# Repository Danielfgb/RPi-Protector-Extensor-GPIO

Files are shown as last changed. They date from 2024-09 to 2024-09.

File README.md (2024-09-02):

# RPi-Protector-Extensor-GPIO
Este proyecto consiste en un módulo diseñado para proteger los pines GPIO de la Raspberry Pi y extender su funcionalidad. El módulo incluye protecciones con diodos Zener y resistencias, un extensor de pines GPIO, la capacidad de conectar un módulo relé, y un módulo de reloj en tiempo real (RTC) DS3231.

## Características:

- Protección de GPIO: Cada pin GPIO está protegido con un diodo Zener y una resistencia de 330 ohms, protegiendo los pines de la Raspberry Pi contra sobretensiones y corrientes excesivas.
- Extensión de Pines GPIO: Se incluye un extensor de pines GPIO que permite la conexión de más dispositivos o módulos adicionales.
Compatibilidad con Módulo Relé.
- RTC DS3231: Se ha agregado un módulo de reloj en tiempo real (RTC) DS3231 para mantener el tiempo con alta precisión incluso cuando la Raspberry Pi está apagada.
- Indicadores LED: Se incluyen LEDs de estado en los pines GPIO sin un consumo excesivo de corriente.

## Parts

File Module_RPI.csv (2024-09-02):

Reference | Value | Footprint | Datasheet | Description | Enlace de compra | Package | Cdad
3.3V1, 3.3V2 | Conn_01x02 | Connector_Molex:Molex_KK-254_AE-6410-02A_1x02_P2.54mm_Vertical | ~ | Conector molex P2.54mm |  | THT 2.54mm | 2
5V1, 5V2 | Conn_01x02 | Connector_Molex:Molex_KK-254_AE-6410-02A_1x02_P2.54mm_Vertical | ~ | Conector molex P2.54mm |  | THT 2.54mm | 2
BT1 | Battery | Battery:BatteryHolder_Seiko_MS621F | ~ | Bateria 3v |  |  | 1
C1, C2 | 100nF | Capacitor_SMD:C_0805_2012Metric | ~ | Condensador SMD 0805 100nF |  | 0805 | 2
D1, D30-D58 | LED | LED_SMD:LED_1206_3216Metric | ~ | LED SMD 1206 | https://www.vistronica.com/componentes-activos/diodos/led/led-verde-smd-1206-x10-detail.html | 1206 | 30
D2-D29 | BZT52Bxx | Diode_SMD:D_SOD-123F | https://www.alldatasheet.com/view.jsp?Searchword=Bzt52c3v3 | Diodo zener 3.3v SMD SOD-123F | https://www.vistronica.com/nuevo-compras-diodo-zener-33v-bzt52c3v3s-0805-detail.html | SOD-123F | 28
GPIO16, GPIO18, GPIO22, GPIO24, GPIO26, GPIO28 | Conn_01x02 | Connector_Molex:Molex_KK-254_AE-6410-02A_1x02_P2.54mm_Vertical | ~ | Conector molex P2.54mm |  | THT | 6
GPIO29 | Conn_01x03 | Connector_Molex:Molex_KK-254_AE-6410-03A_1x03_P2.54mm_Vertical | ~ | Conector molex P2.54mm |  | THT | 1
J1 | Conn_01x02_Pin | Connector_PinHeader_2.54mm:PinHeader_1x02_P2.54mm_Vertical | ~ |  |  |  | 1
J1_Rele1 | Conn_02x20_Odd_Even | Connector_PinHeader_2.54mm:PinHeader_2x20_P2.54mm_Vertical | ~ | Header macho macho 2.54mm (2x20P) | https://www.vistronica.com/conectores-cables-y-switches/regleta-conector-140p-2-54mm-macho-macho-detail.html | THT | 1
J2, J4 | Conn_01x20 | Connector_PinHeader_2.54mm:PinHeader_1x20_P2.54mm_Vertical | ~ | Header macho macho 2.54 mm (1x20P) | https://www.vistronica.com/conectores-cables-y-switches/regleta-conector-140p-2-54mm-macho-macho-detail.html | THT | 2
JP1-JP28 | Jumper_3_Bridged12 | Jumper:SolderJumper-3_P1.3mm_Open_Pad1.0x1.5mm | ~ | Pista para soldar jumper |  | None | 28
JP30 | Jumper_2_Open | Jumper:SolderJumper-2_P1.3mm_Open_RoundedPad1.0x1.5mm | ~ |  |  |  | 1
R1, R59 | 4.7K | Resistor_SMD:R_1206_3216Metric | ~ | Resistencia SMD 1206 4.7K |  | 1206 | 2
R2, R32-R58, R60-R62 | 10K | Resistor_SMD:R_1206_3216Metric | ~ | -- valores mixtos -- | -- valores mixtos -- | -- valores mixtos -- | 31
R3-R30 | 330R | Resistor_SMD:R_1206_3216Metric_Pad1.30x1.75mm_HandSolder | ~ | Resistencia SMD 1206 330 | https://www.vistronica.com/componentes-pasivos/resistencias/resistencias-330-ohm-smd-1206-14w-5-x10-detail.html | 1206 | 28
R31 | 1K | Resistor_SMD:R_1206_3216Metric | ~ | Resistencia SMD 1206 1K | https://www.vistronica.com/componentes-pasivos/resistencias/resistencias-1-kohm-smd-1206-14w-5-x10-detail.html | 1206 | 1
SW1 | SW_Push | Button_Switch_SMD:SW_SPST_TL3342 | ~ |  |  |  | 1
U1 | DS3231M | Package_SO:SOIC-16W_7.5x10.3mm_P1.27mm | http://datasheets.maximintegrated.com/en/ds/DS3231.pdf | RTC DS3231M |  | SOIC | 1
U2 | RASPBERRY_PI_4B_4GB | RASPBERRY_PI_4B_4GB:MODULE_RASPBERRY_PI_4B_4GB |  | Regleta HEMBRA 2.54mm (2X20P) | https://www.vistronica.com/conectores-cables-y-switches/regleta-hembra-254mm-2x20p-detail.html | None | 1

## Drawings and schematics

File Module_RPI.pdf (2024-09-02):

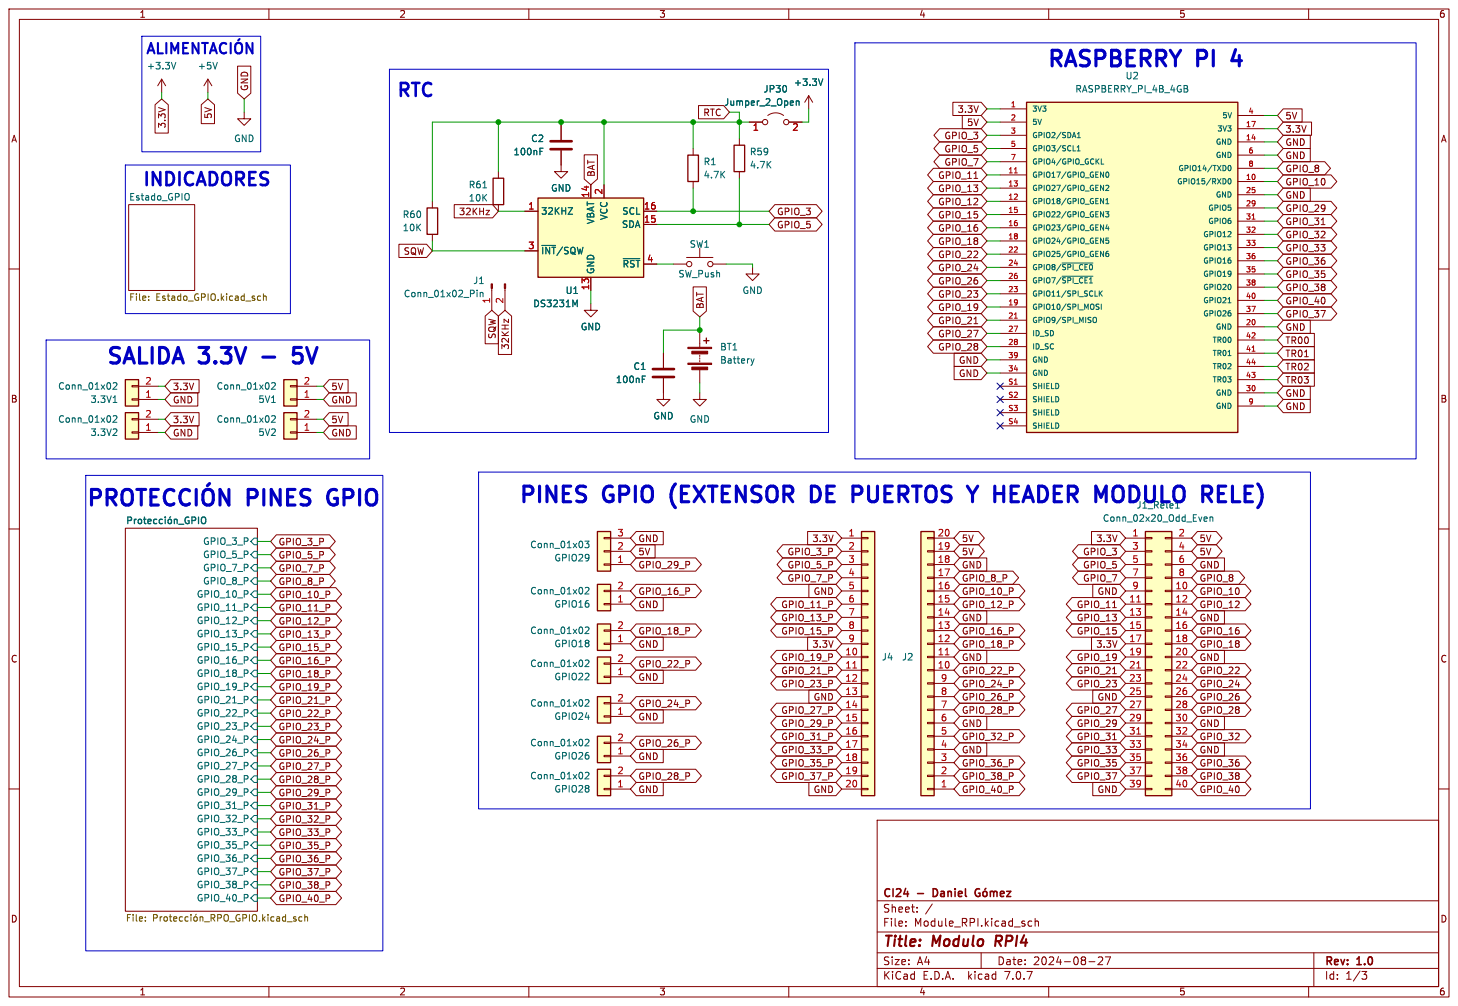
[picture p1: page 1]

PINES GPIO (EXTENSOR DE PUERTOS Y HEADER MODULO RELE)

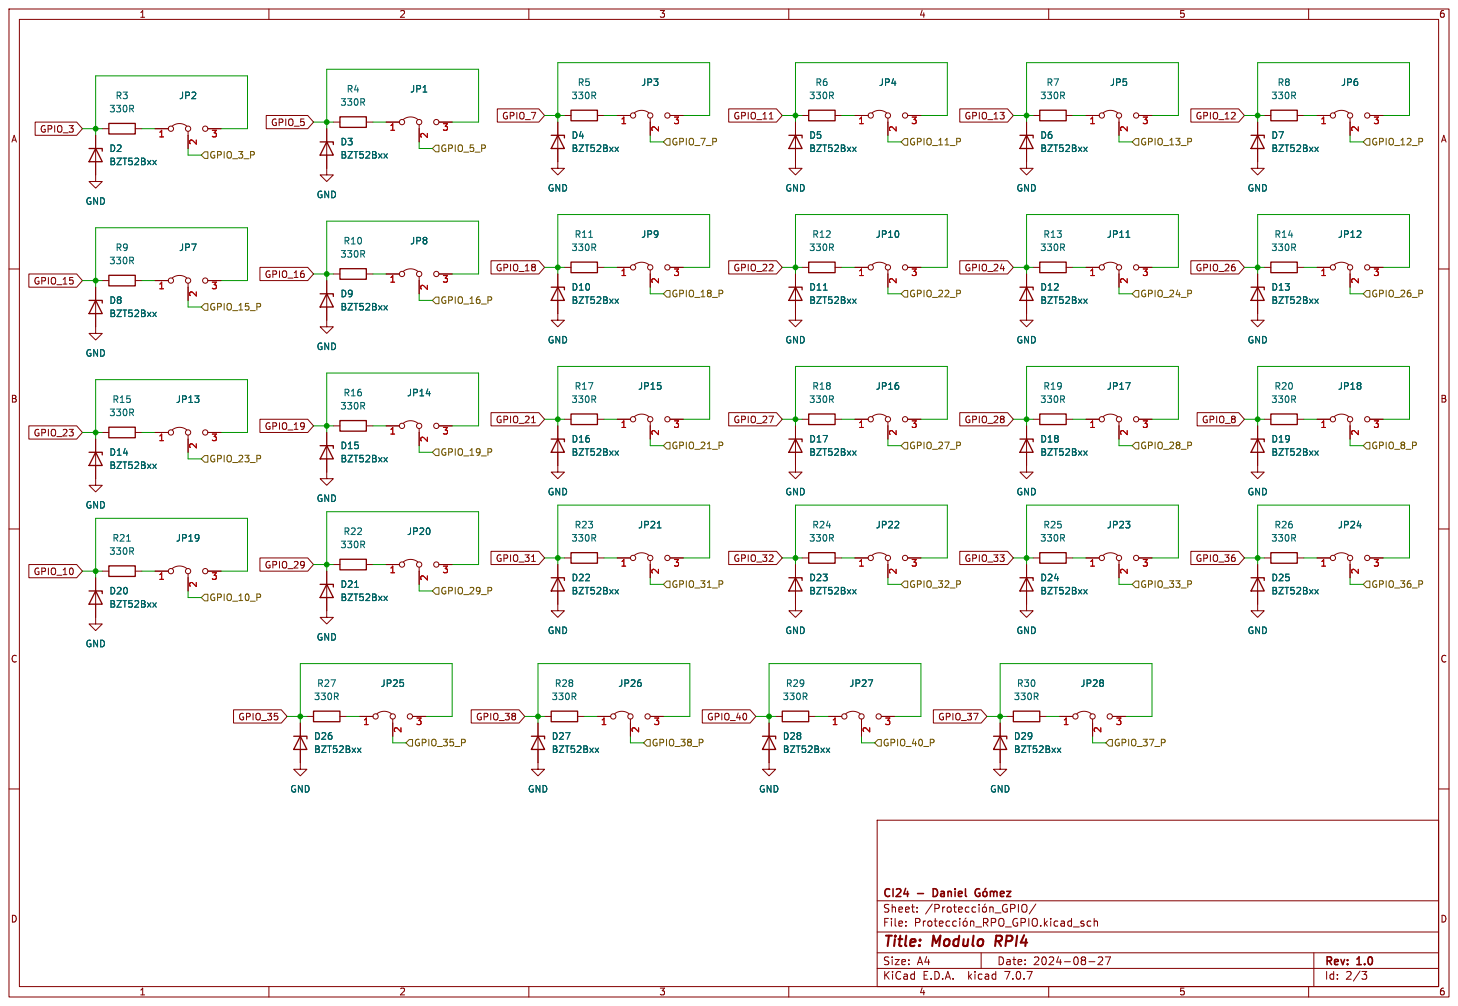
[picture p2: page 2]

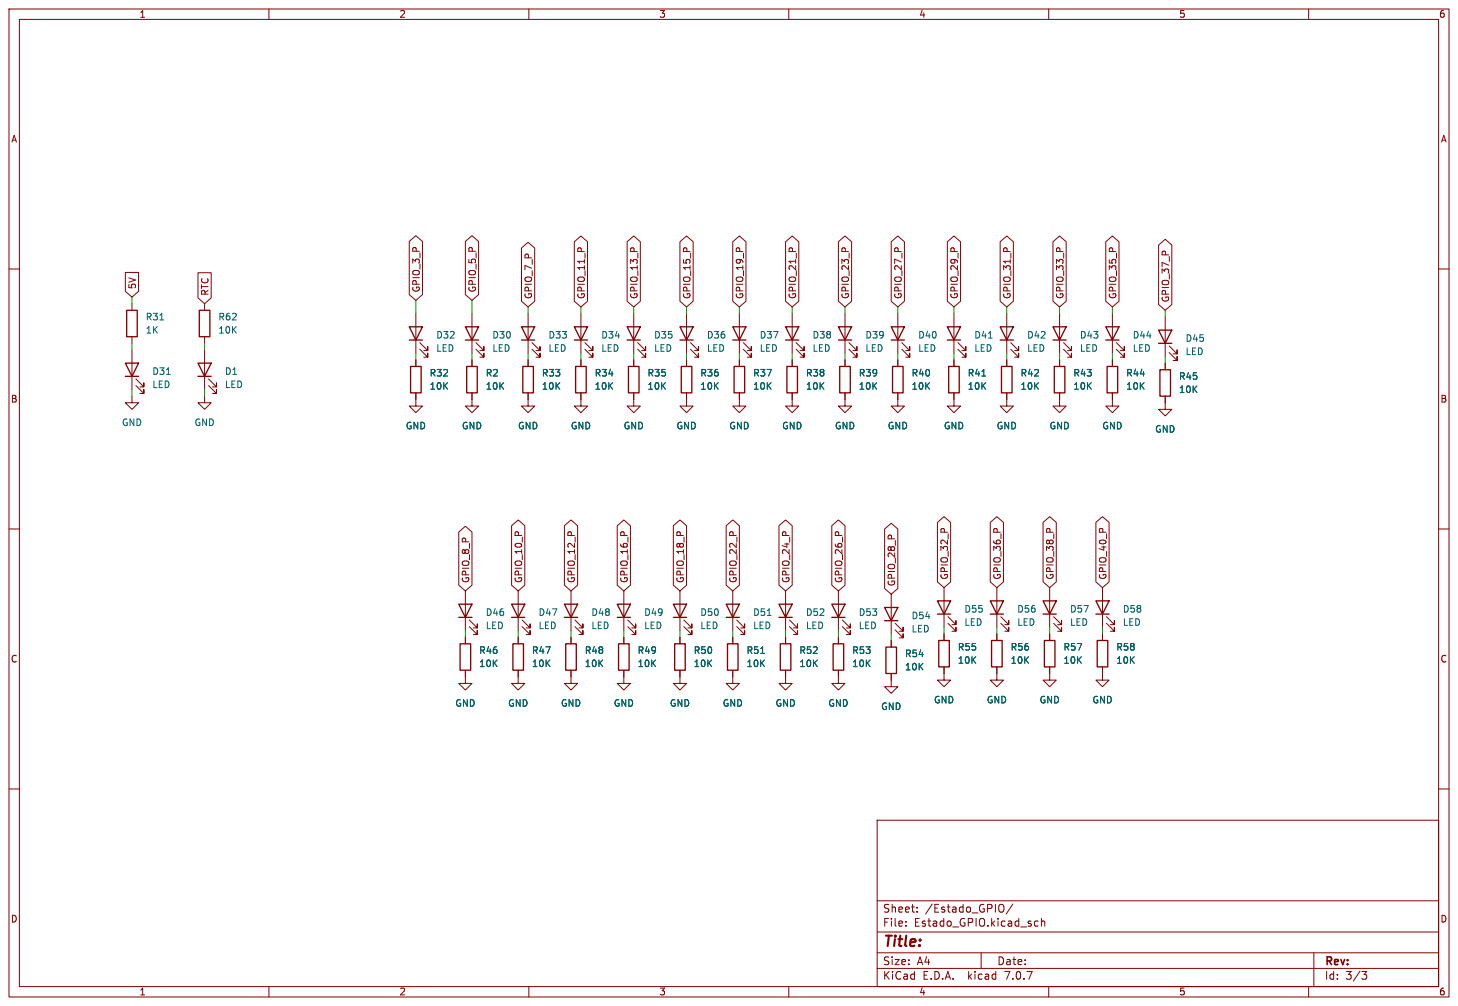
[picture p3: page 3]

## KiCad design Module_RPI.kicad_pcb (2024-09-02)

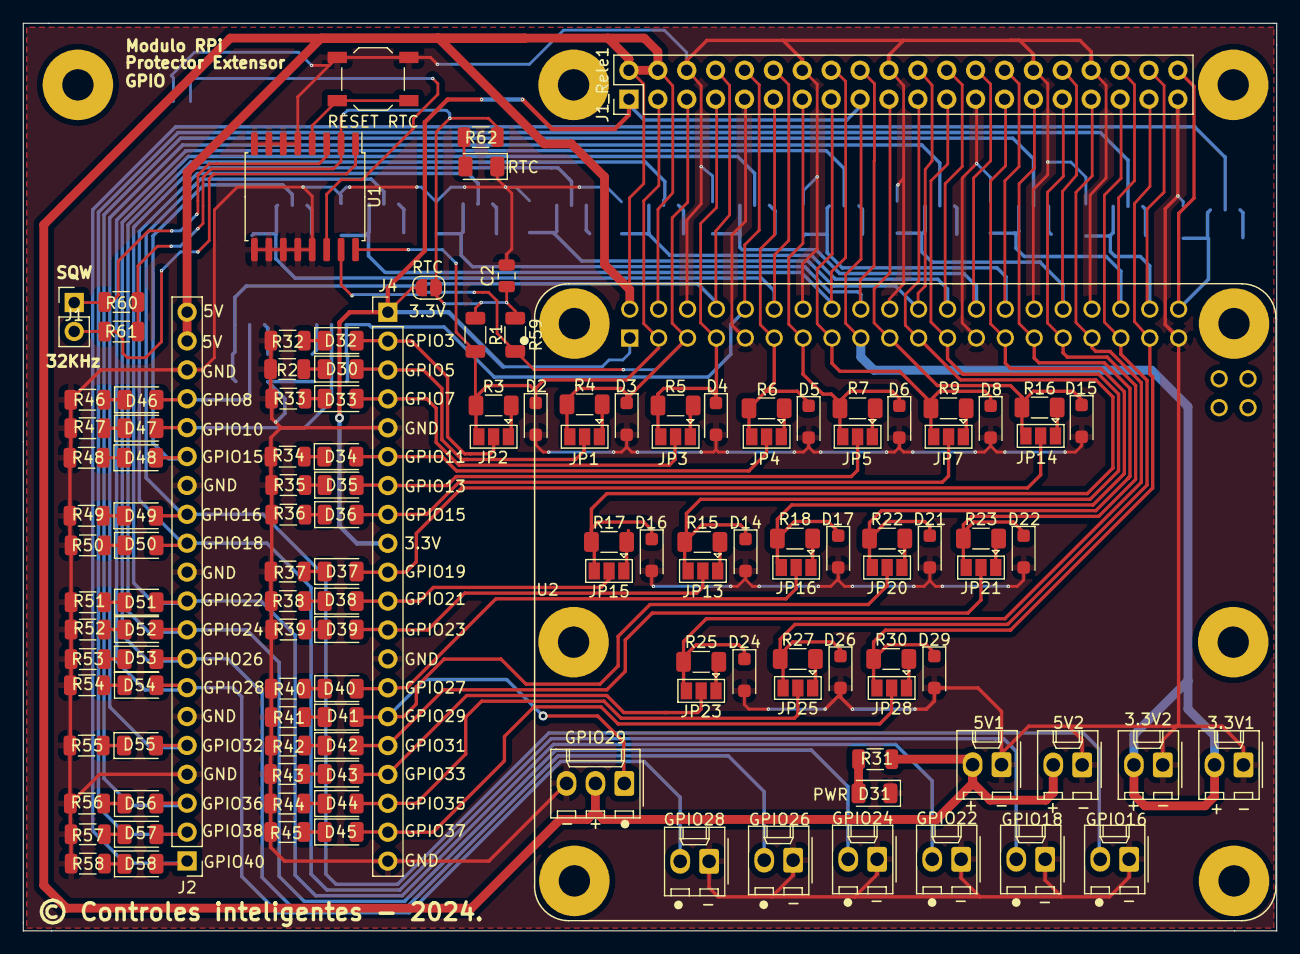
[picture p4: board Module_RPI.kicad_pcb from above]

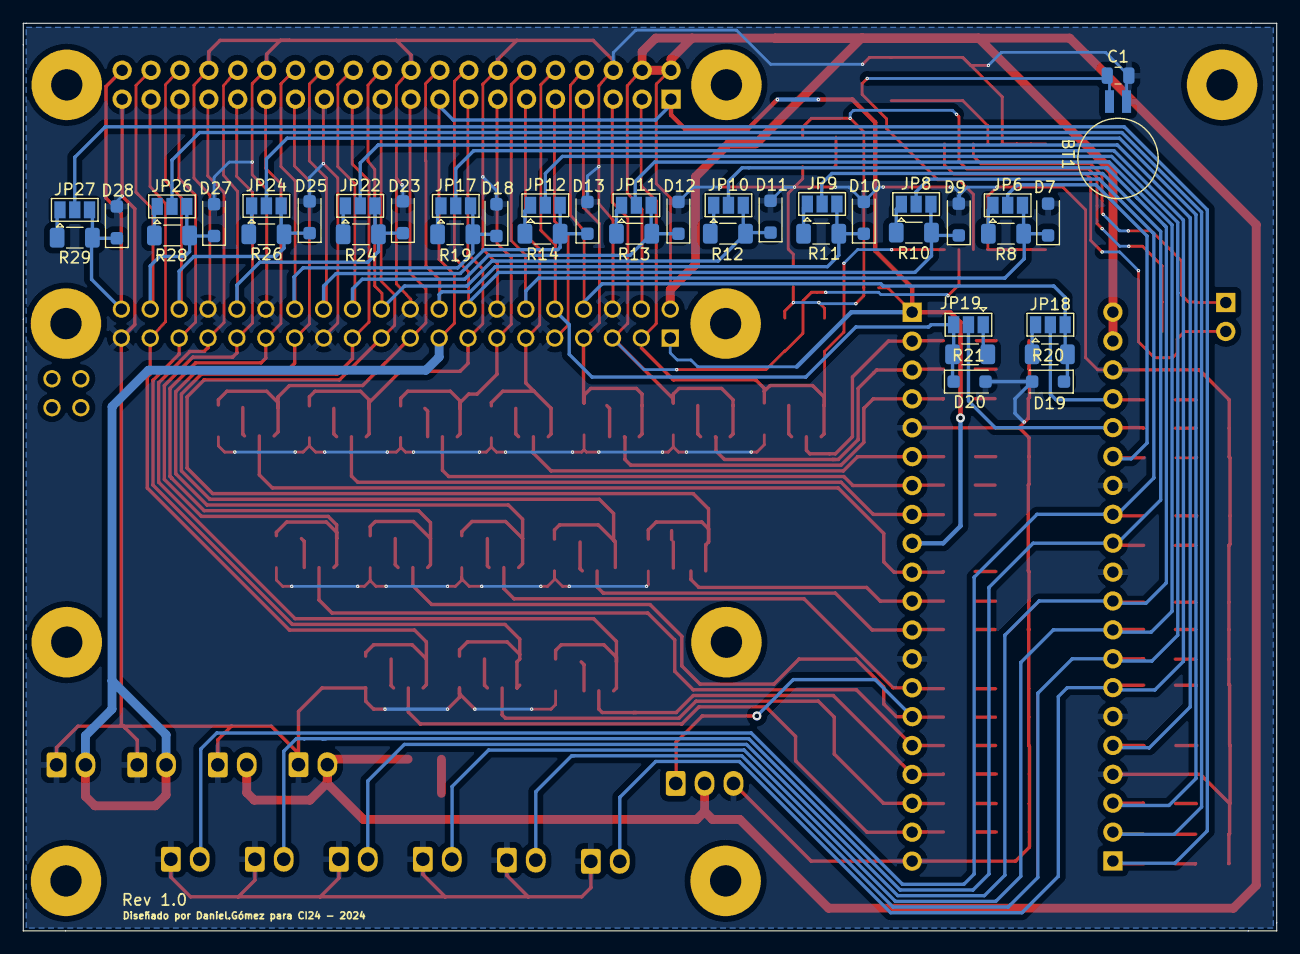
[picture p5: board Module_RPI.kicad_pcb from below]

Board: 2 copper layers, 110.2 x 79.8 mm, 170 parts (41 on the bottom side), 122 nets.

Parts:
3.3V1, 3.3V2, 5V1, 5V2: Conn_01x02; Molex_KK-254_AE-6410-02A_1x02_P2.54mm_Vertical
BT1: Battery; BatteryHolder_Seiko_MS621F
C1, C2: 100nF; C_0805_2012Metric
D2, D3, D4, D5, D6, D7, D8, D9, D10, D11, D12, D13, D14, D15, D16, D17, D18, D19, D20, D21, D22, D23, D24, D25, D26, D27, D28, D29: BZT52Bxx; D_SOD-123F
D30, D31, D32, D33, D34, D35, D36, D37, D38, D39, D40, D41, D42, D43, D44, D45, D46, D47, D48, D49, D50, D51, D52, D53, D54, D55, D56, D57, D58: LED; LED_1206_3216Metric
GPIO16, GPIO18, GPIO22, GPIO24, GPIO26, GPIO28: Conn_01x02; Molex_KK-254_AE-6410-02A_1x02_P2.54mm_Vertical
GPIO29: Conn_01x03; Molex_KK-254_AE-6410-03A_1x03_P2.54mm_Vertical
J1: Conn_01x02_Pin; PinHeader_1x02_P2.54mm_Vertical
J1_Rele1: Conn_02x20_Odd_Even; PinHeader_2x20_P2.54mm_Vertical
J2, J4: Conn_01x20; PinHeader_1x20_P2.54mm_Vertical
JP1, JP2, JP3, JP4, JP5, JP6, JP7, JP8, JP9, JP10, JP11, JP12, JP13, JP14, JP15, JP16, JP17, JP18, JP19, JP20, JP21, JP22, JP23, JP24, JP25, JP26, JP27, JP28: Jumper_3_Bridged12; SolderJumper-3_P1.3mm_Open_Pad1.0x1.5mm
R1, R59: 4.7K; R_1206_3216Metric
R2, R32, R33, R34, R35, R36, R37, R38, R39, R40, R41, R42, R43, R44, R45, R46, R47, R48, R49, R50, R51, R52, R53, R54, R55, R56, R57, R58, R60, R61, R62: 10K; R_1206_3216Metric
R3, R4, R5, R6, R7, R8, R9, R10, R11, R12, R13, R14, R15, R16, R17, R18, R19, R20, R21, R22, R23, R24, R25, R26, R27, R28, R29, R30: 330R; R_1206_3216Metric_Pad1.30x1.75mm_HandSolder
R31: 1K; R_1206_3216Metric
RESET RTC: SW_Push; SW_SPST_TL3342
RTC: LED; LED_1206_3216Metric
RTC#2: Jumper_2_Open; SolderJumper-2_P1.3mm_Open_RoundedPad1.0x1.5mm
U1: DS3231M; SOIC-16W_7.5x10.3mm_P1.27mm
U2: RASPBERRY_PI_4B_4GB; MODULE_RASPBERRY_PI_4B_4GB

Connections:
3.3V: 3.3V1.2, 3.3V2.2, J1_Rele1.1, J1_Rele1.17, J4.1, J4.9, RTC#2.2 (B), U2.1 (3V3), U2.17 (3V3)
5V: 5V1.2, 5V2.2, GPIO29.2, J1_Rele1.2, J1_Rele1.4, J2.19, J2.20, R31.1, U2.2 (5V), U2.4 (5V)
32KHz: J1.2, R61.2, U1.1 (32KHZ)
BAT: BT1.1 (+), C1.1, U1.14 (VBAT)
GND: 3.3V1.1, 3.3V2.1, 5V1.1, 5V2.1, BT1.2 (-), C1.2, C2.2, D2.2 (A), D3.2 (A), D4.2 (A), D5.2 (A), D6.2 (A), D7.2 (A), D8.2 (A), D9.2 (A), D10.2 (A), D11.2 (A), D12.2 (A), D13.2 (A), D14.2 (A), D15.2 (A), D16.2 (A), D17.2 (A), D18.2 (A), D19.2 (A), D20.2 (A), D21.2 (A), D22.2 (A), D23.2 (A), D24.2 (A), D25.2 (A), D26.2 (A), D27.2 (A), D28.2 (A), D29.2 (A), D31.1 (K), GPIO16.1, GPIO18.1, GPIO22.1, GPIO24.1, GPIO26.1, GPIO28.1, GPIO29.3, J1_Rele1.6, J1_Rele1.9, J1_Rele1.14, J1_Rele1.20, J1_Rele1.25, J1_Rele1.30, J1_Rele1.34, J1_Rele1.39, J2.4, J2.6, J2.11, J2.14, J2.18, J4.5, J4.13, J4.20, R2.2, R32.2, R33.2, R34.2, R35.2, R36.2, R37.2, R38.2, R39.2, R40.2, R41.2, R42.2, R43.2, R44.2, R45.2, R46.2, R47.2, R48.2, R49.2, R50.2, R51.2, R52.2, R53.2, R54.2, R55.2, R56.2, R57.2, R58.2, RESET RTC.2, RTC.1 (K), U1.5 (GND), U1.6 (GND), U1.7 (GND), U1.8 (GND), U1.9 (GND), U1.10 (GND), U1.11 (GND), U1.12 (GND), U1.13 (GND), U2.6 (GND), U2.9 (GND), U2.14 (GND), U2.20 (GND), U2.25 (GND), U2.30 (GND), U2.34 (GND), U2.39 (GND)
GPIO_3: D2.1 (K), J1_Rele1.3, JP2.3 (B), R1.2, R3.2, U1.16 (SCL), U2.3 (GPIO2/SDA1)
GPIO_3_P: D32.2 (A), J4.2, JP2.2 (C)
GPIO_5: D3.1 (K), J1_Rele1.5, JP1.3 (B), R4.2, R59.2, U1.15 (SDA), U2.5 (GPIO3/SCL1)
GPIO_5_P: D30.2 (A), J4.3, JP1.2 (C)
GPIO_7: D4.1 (K), J1_Rele1.7, JP3.3 (B), R5.2, U2.7 (GPIO4/GPIO_GCKL)
GPIO_7_P: D33.2 (A), J4.4, JP3.2 (C)
GPIO_8: D19.1 (K), J1_Rele1.8, JP18.3 (B), R20.2, U2.8 (GPIO14/TXD0)
GPIO_8_P: D46.2 (A), J2.17, JP18.2 (C)
GPIO_10: D20.1 (K), J1_Rele1.10, JP19.3 (B), R21.2, U2.10 (GPIO15/RXD0)
GPIO_10_P: D47.2 (A), J2.16, JP19.2 (C)
GPIO_11: D5.1 (K), J1_Rele1.11, JP4.3 (B), R6.2, U2.11 (GPIO17/GPIO_GEN0)
GPIO_11_P: D34.2 (A), J4.6, JP4.2 (C)
GPIO_12: D7.1 (K), J1_Rele1.12, JP6.3 (B), R8.2, U2.12 (GPIO18/GPIO_GEN1)
GPIO_12_P: D48.2 (A), J2.15, JP6.2 (C)
GPIO_13: D6.1 (K), J1_Rele1.13, JP5.3 (B), R7.2, U2.13 (GPIO27/GPIO_GEN2)
GPIO_13_P: D35.2 (A), J4.7, JP5.2 (C)
GPIO_15: D8.1 (K), J1_Rele1.15, JP7.3 (B), R9.2, U2.15 (GPIO22/GPIO_GEN3)
GPIO_15_P: D36.2 (A), J4.8, JP7.2 (C)
GPIO_16: D9.1 (K), J1_Rele1.16, JP8.3 (B), R10.2, U2.16 (GPIO23/GPIO_GEN4)
GPIO_16_P: D49.2 (A), GPIO16.2, J2.13, JP8.2 (C)
GPIO_18: D10.1 (K), J1_Rele1.18, JP9.3 (B), R11.2, U2.18 (GPIO24/GPIO_GEN5)
GPIO_18_P: D50.2 (A), GPIO18.2, J2.12, JP9.2 (C)
GPIO_19: D15.1 (K), J1_Rele1.19, JP14.3 (B), R16.2, U2.19 (GPIO10/SPI_MOSI)
GPIO_19_P: D37.2 (A), J4.10, JP14.2 (C)
GPIO_21: D16.1 (K), J1_Rele1.21, JP15.3 (B), R17.2, U2.21 (GPIO9/SPI_MISO)
GPIO_21_P: D38.2 (A), J4.11, JP15.2 (C)
GPIO_22: D11.1 (K), J1_Rele1.22, JP10.3 (B), R12.2, U2.22 (GPIO25/GPIO_GEN6)
GPIO_22_P: D51.2 (A), GPIO22.2, J2.10, JP10.2 (C)
GPIO_23: D14.1 (K), J1_Rele1.23, JP13.3 (B), R15.2, U2.23 (GPIO11/SPI_SCLK)
GPIO_23_P: D39.2 (A), J4.12, JP13.2 (C)
GPIO_24: D12.1 (K), J1_Rele1.24, JP11.3 (B), R13.2, U2.24 (GPIO8/~SPI_CE0)
GPIO_24_P: D52.2 (A), GPIO24.2, J2.9, JP11.2 (C)
GPIO_26: D13.1 (K), J1_Rele1.26, JP12.3 (B), R14.2, U2.26 (GPIO7/~SPI_CE1)
GPIO_26_P: D53.2 (A), GPIO26.2, J2.8, JP12.2 (C)
GPIO_27: D17.1 (K), J1_Rele1.27, JP16.3 (B), R18.2, U2.27 (ID_SD)
GPIO_27_P: D40.2 (A), J4.14, JP16.2 (C)
GPIO_28: D18.1 (K), J1_Rele1.28, JP17.3 (B), R19.2, U2.28 (ID_SC)
GPIO_28_P: D54.2 (A), GPIO28.2, J2.7, JP17.2 (C)
GPIO_29: D21.1 (K), J1_Rele1.29, JP20.3 (B), R22.2, U2.29 (GPIO5)
GPIO_29_P: D41.2 (A), GPIO29.1, J4.15, JP20.2 (C)
GPIO_31: D22.1 (K), J1_Rele1.31, JP21.3 (B), R23.2, U2.31 (GPIO6)
GPIO_31_P: D42.2 (A), J4.16, JP21.2 (C)
GPIO_32: D23.1 (K), J1_Rele1.32, JP22.3 (B), R24.2, U2.32 (GPIO12)
GPIO_32_P: D55.2 (A), J2.5, JP22.2 (C)
GPIO_33: D24.1 (K), J1_Rele1.33, JP23.3 (B), R25.2, U2.33 (GPIO13)
GPIO_33_P: D43.2 (A), J4.17, JP23.2 (C)
GPIO_35: D26.1 (K), J1_Rele1.35, JP25.3 (B), R27.2, U2.35 (GPIO19)
GPIO_35_P: D44.2 (A), J4.18, JP25.2 (C)
GPIO_36: D25.1 (K), J1_Rele1.36, JP24.3 (B), R26.2, U2.36 (GPIO16)
GPIO_36_P: D56.2 (A), J2.3, JP24.2 (C)
GPIO_37: D29.1 (K), J1_Rele1.37, JP28.3 (B), R30.2, U2.37 (GPIO26)
GPIO_37_P: D45.2 (A), J4.19, JP28.2 (C)
GPIO_38: D27.1 (K), J1_Rele1.38, JP26.3 (B), R28.2, U2.38 (GPIO20)
GPIO_38_P: D57.2 (A), J2.2, JP26.2 (C)
GPIO_40: D28.1 (K), J1_Rele1.40, JP27.3 (B), R29.2, U2.40 (GPIO21)
GPIO_40_P: D58.2 (A), J2.1, JP27.2 (C)
unnamed: R62.2, RTC.2 (A)
unnamed: D30.1 (K), R2.1
unnamed: D31.2 (A), R31.2
unnamed: D32.1 (K), R32.1
unnamed: D33.1 (K), R33.1
unnamed: D34.1 (K), R34.1
unnamed: D35.1 (K), R35.1
unnamed: D36.1 (K), R36.1
unnamed: D37.1 (K), R37.1
unnamed: D38.1 (K), R38.1
unnamed: D39.1 (K), R39.1
unnamed: D40.1 (K), R40.1
unnamed: D41.1 (K), R41.1
unnamed: D42.1 (K), R42.1
unnamed: D43.1 (K), R43.1
unnamed: D44.1 (K), R44.1
unnamed: D45.1 (K), R45.1
unnamed: D46.1 (K), R46.1
unnamed: D47.1 (K), R47.1
unnamed: D48.1 (K), R48.1
unnamed: D49.1 (K), R49.1
unnamed: D50.1 (K), R50.1
unnamed: D51.1 (K), R51.1
unnamed: D52.1 (K), R52.1
unnamed: D53.1 (K), R53.1
unnamed: D54.1 (K), R54.1
unnamed: D55.1 (K), R55.1
unnamed: D56.1 (K), R56.1
unnamed: D57.1 (K), R57.1
unnamed: D58.1 (K), R58.1
unnamed: JP1.1 (A), R4.1
unnamed: JP2.1 (A), R3.1
unnamed: JP3.1 (A), R5.1
unnamed: JP4.1 (A), R6.1
unnamed: JP5.1 (A), R7.1
unnamed: JP6.1 (A), R8.1
unnamed: JP7.1 (A), R9.1
unnamed: JP8.1 (A), R10.1
unnamed: JP9.1 (A), R11.1
unnamed: JP10.1 (A), R12.1
unnamed: JP11.1 (A), R13.1
unnamed: JP12.1 (A), R14.1
unnamed: JP13.1 (A), R15.1
unnamed: JP14.1 (A), R16.1
unnamed: JP15.1 (A), R17.1
unnamed: JP16.1 (A), R18.1
unnamed: JP17.1 (A), R19.1
unnamed: JP18.1 (A), R20.1
unnamed: JP19.1 (A), R21.1
unnamed: JP20.1 (A), R22.1
unnamed: JP21.1 (A), R23.1
unnamed: JP22.1 (A), R24.1
unnamed: JP23.1 (A), R25.1
unnamed: JP24.1 (A), R26.1
unnamed: JP25.1 (A), R27.1
unnamed: JP26.1 (A), R28.1
unnamed: JP27.1 (A), R29.1
unnamed: JP28.1 (A), R30.1
unnamed: RESET RTC.1, U1.4 (~RST)
RTC: C2.1, R1.1, R59.1, R60.1, R61.1, R62.1, RTC#2.1 (A), U1.2 (VCC)
SQW: J1.1, R60.2, U1.3 (~INT/SQW)

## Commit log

2024-08-30 :sparkles: Archivos de diseño de PCB
    [Estado_GPIO.kicad_sch, Module_RPI.kicad_pcb, Module_RPI.kicad_sch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]
2024-08-30 :sparkles: Gerber y lista de componentes
    [Module_RPI-B_Cu.gbr, Module_RPI-B_Mask.gbr, Module_RPI-B_Paste.gbr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]
2024-09-02 Actualización Modulo RPI
    [Estado_GPIO.kicad_sch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]
2024-09-02 Actualización archivo kicad

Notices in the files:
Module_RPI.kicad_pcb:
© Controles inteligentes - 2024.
